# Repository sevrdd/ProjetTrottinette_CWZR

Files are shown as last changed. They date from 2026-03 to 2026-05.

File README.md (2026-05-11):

# Projet Trottinette

Projet éffectué par: Zachary Roy et William Champagne

Ce projet entreprend la conception d'un écran de tableau de bord pour une trottinette électrique. Ce tableau de bord est capable d'afficher les informations concernant la trottinette de façon efficace et précise sur un écran.

## Prérequis
Une trottinette fonctionelle à laquelle le module de tableau de bord est branché.

### Matériel
**1.** Boitier

**2.** PCB    

**3.** Écran (raspberry PI)

### Logiciel
**1.** STM32CubeIDE, CubeMX et VsCode
    - Tkinter et Pillow doivent être installé  
    
    pip install Pillow
    pip install tk 

**1.** Altium -> PCB 
    - Librairie Celestial utilisée
    - Librairie étudiante utilisée

**3.** Fusion 360 -> Modèle 3D 

### Limitations
L'affichage est limité à une vitesse de rafraîchissement de 5 Hz.

La version actuelle est limitée à une utilisation stationnaire dû à l'écran HDMI nécessitant une station fixe.

## Structure

### 3DModels
Cette section regroupe les [modèles 3D](<3DModels/>) nécessaires pour la fabrication et la manufacturation du PCB et du support associé à ce même PCB.

**1.** Modèle 3D de la [carte du tableau de bord.](<3DModels/>)

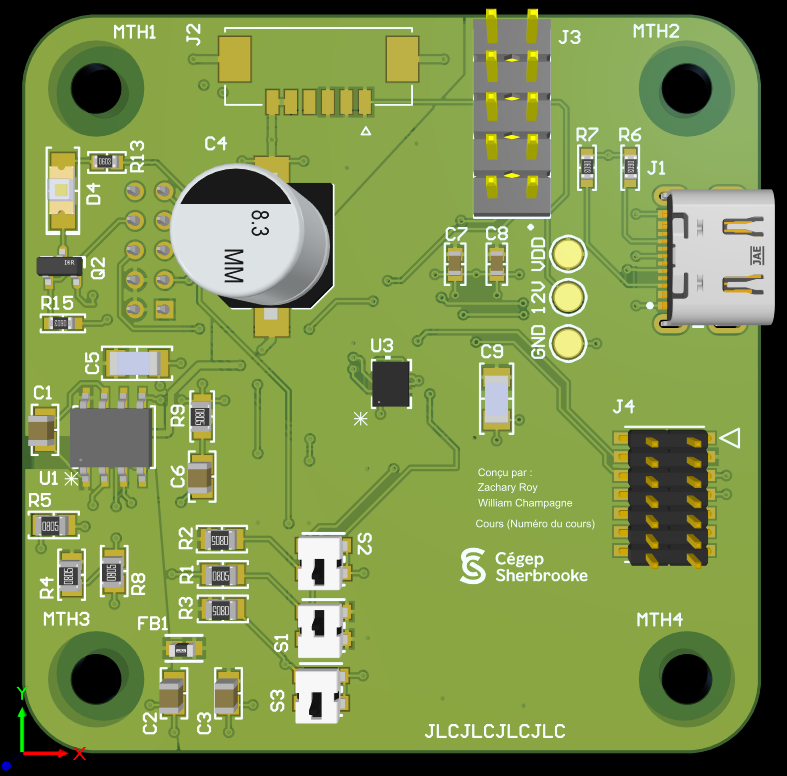
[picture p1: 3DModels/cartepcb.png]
Carte PCB


**2.** Modèle 3D du [support](<3DModels/>) pour la carte du tableau de bord et le raspberry pi. 

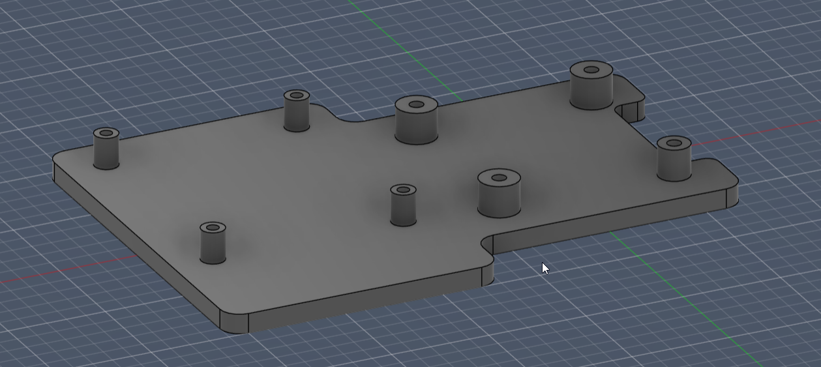
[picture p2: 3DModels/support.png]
Support


### Code
Cette section contient les fichiers code du [STM32](<Code/STM32/>) et du [Raspberry Pi](<Code/STM32/>)

- #### Raspberry Pi 3b
**tk_main.py** code gérant l'affichage de l'interface de l'utilisateur et la communication UART. 

**icons** fichier contenant les icones nécessaire pour l'affichage de l'interface utilisateur.

- #### STM32

**stm32_main.c** code "pass through" de l'information uart, faisant le pont entre la carte de contrôle et le raspberry pi.

### Datasheets
Cette section contient les diverses [datasheets](<Datasheets/>) utilisées pour la conception du schéma électrique. 

### Guides
Cette section contient les [guides](<Guides/>) pour utilisateur et développeur.

### Journal

Cette section contient le [journal](<Journal/>) de bord, la distribution des tâches au travers de la journée, les difficultés rencontrées ainsi que les solutions trouvées à ces mêmes problèmes.

### PCB
Cette [section](<PCB/>) contient les divers [symboles, footprints et modèles](<PCB/Symbols, footprints and models>) nécessaire pour la conception de la carte PCB ainsi que le plan de test complété. 

#### Fichier des symboles, footprints et modèles
- Fichier contenant les éléments nécessaires pour la conception de la carte PCB.

#### Plan de test
- Plan de test complété.

### Schéma
La section ["Schematics"](<Schematics/>) du dépôt github contient les shémas suivant : 

**1.** Shéma bloc *Vielle version* 

**2.** Shéma électrique 

**3.** Ordinogramme | Pour le code du raspberry pi 

## Utilisation
**1.** Brancher et allumer les composantes

**2.** Lancer le logiciel *tk_main.exe* (À faire un executable du code python)

**3.** Utiliser la trottinette

### Code STM32 et Python
La section "Code" du dépôt github contient les codes suivant : 
- stm32_main.c -> Code main du microcontrolleur STM32.
- tk_main.py -> Code python pour l'écran.

### Pour un utilisateur
Voir [Guide d'utilisateur](<Guides/guide_user.md>)

### Pour un developpeur
Voir [Guide de développement](<Guides/guide_dev.md>)

### Modifications à faire
- Révision du PCB
     - Changement du régulateur
           - 12V -> 5V Switching Régulateur, 5V -> 3V3 Régulateur LDO. Cela nous permet d'intégrer l'alimentation par USB-C  
     - Changer les branchements du connecteur de debug
- Boitié étanche
- Remplacer le Raspberry PI avec un écran adapter pour une trottinette. Cette modification nous rapprocherait du projet initiale décris par le client.
      - Nécessite un changement du code, du schéma électrique (+ Routage) et du boitié. Cela est donc une modification plus importante à faire lorsque les autres modifications sont éffectuées.

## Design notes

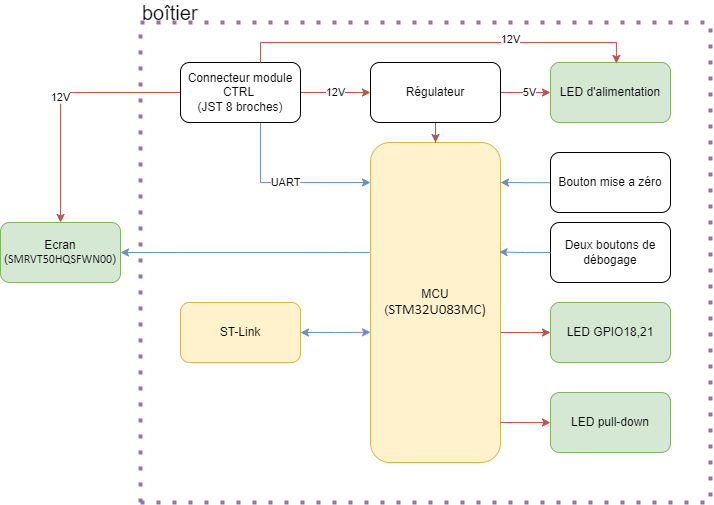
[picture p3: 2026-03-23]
Schematics/Shéma bloc.png

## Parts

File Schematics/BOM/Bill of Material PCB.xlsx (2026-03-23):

Bill of Material
Board | 1 |  | Concepteur Principal |  | Zachary Roy |  |  | 1
Cours | Cours (Numéro du cours) |  | Date du projet |  | 2026-02-26 |  |  | 00
Département | Technologies du génie électrique |  | Date de génération du BOM |  | 2026-02-26
Révision | 1.00 |  | Heure de génération du BOM |  | 4:27 PM
Nombre de PCB | 1 |  | Variant |  | None
Item # | Designator | #Column Name Error:' Layer | Description | Comment | Package / Case | Supplier 1 | Supplier Part Number 1 | Quantity | Quantity Total | Note
1 | C1 |  | CAP CER 0.1UF 50V X7R 0805 | 0.1 µF | 0805 (2012 Metric) | DigiKey | 311-4351-1-ND | 1 | 1
2 | C2, C3 |  | CAP CER 10UF 25V X5R 0805 | 10µF | 0805 (2012 Metric) | DigiKey | 478-10492-1-ND | 2 | 2
3 | C4 |  | CAP ALUM 100UF 20% 50V SMD | 100 µF | Radial, Can - SMD | DigiKey | 493-2226-1-ND | 1 | 1
4 | C5, C9 |  | CAP CER 10UF 100V X6S 1206 | 10 µF | 1206 (3216 Metric) | DigiKey | 445-C3216X6S2A106K160ACCT-ND | 2 | 2
5 | C6 |  | CAP CER 6800PF 50V X7R 0805 | 6800pF | 0805 (2012 Metric) | DigiKey | 478-1381-1-ND | 1 | 1
6 | C7 |  | CAP CER 4.7UF 25V X5R 0603 | 4.7 µF | 0603 (1608 Metric) | DigiKey | 1276-1900-1-ND | 1 | 1
7 | C8 |  | CAP CER 0.1UF 50V X7R 0603 | 0.1 µF | 0603 (1608 Metric) | DigiKey | 399-C0603C104K5RAC7411CT-ND | 1 | 1
8 | D1, D2 |  | LED GREEN DIFFUSED 1608 SMD | Green | 0603 (1608 Metric) | DigiKey | 846-SML-D12P8WT86CT-ND | 2 | 2
9 | D3, D4, D5, D6 |  | LED YELLOW 1206 SMD | Yellow | 1206 (3216 Metric) | DigiKey | 350-4363-1-ND | 4 | 4
10 | FB1 |  | Chip Ferrite Bead Array, 0603, 120Ω @ 100MHz, 25%, 0.03Ω, 3A | BLM18KG121TZ1D |  |  |  | 1 | 1
11 | J1 |  | CONN RCP USB2.0 TYP C 24P SMD RA | DX07S016JA1R1500 |  |  |  | 1 | 1
12 | J2 |  |  | 532610671 |  |  |  | 1 | 1
13 | J3 |  | Connector Header Through Hole 10 position 0.100" (2.54mm) | TSW-105-07-G-D |  |  |  | 1 | 1
14 | J4 |  | Description | FTSH-107-01-L-DV-K |  |  |  | 1 | 1
15 | J5 |  | CONN HEADER R/A 10POS 2MM | S10B-PHDSS (LF)(SN) |  |  |  | 1 | 1
16 | Q1, Q2 |  | MOSFET N-CH 20V 6.3A SOT-23 | IRLML6244TRPBF |  |  |  | 2 | 2
17 | Q3, Q4 |  | MOSFET P-CH 12V 4.3A SOT-23 | IRLML6401TRPBF |  |  |  | 2 | 2
18 | R1, R2, R3 |  | RES SMD 10K OHM 0.5% 1/4W 0805 | 10 kOhms | 0805 (2012 Metric) | DigiKey | RNCF0805DTE10K0CT-ND | 3 | 3
19 | R4 |  | RES SMD 3K OHM 0.1% 1/4W 0805 | 3 kOhms | 0805 (2012 Metric) | DigiKey | P20646CT-ND | 1 | 1
20 | R5 |  | RES 47K OHM 1% 1/3W 0805 | 47 kOhms | 0805 (2012 Metric) | DigiKey | A130497CT-ND | 1 | 1
21 | R6, R7, R14, R15, R19, R21 |  | RES SMD 5.1K OHM 1% 1/10W 0603 | 5.1 kOhms | 0603 (1608 Metric) | DigiKey | YAG3621CT-ND | 6 | 6
22 | R8 |  | RES SMD 1.3K OHM 0.5% 1/4W 0805 | 1.3 kOhms | 0805 (2012 Metric) | DigiKey | P21031CT-ND | 1 | 1
23 | R9 |  | RES SMD 10K OHM 0.5% 1/8W 0805 | 10 kOhms | 0805 (2012 Metric) | DigiKey | 311-2699-1-ND | 1 | 1
24 | R10 |  | RES SMD 150 OHM 0.1% 1/4W 0805 | 150 Ohms | 0805 (2012 Metric) | DigiKey | A110464CT-ND | 1 | 1
25 | R11 |  | RES SMD 500 OHM 0.05% 1/4W 0805 | 500 Ohms | 0805 (2012 Metric) | DigiKey | PLT0805-500ACT-ND | 1 | 1
26 | R12, R13, R18, R20 |  | RES SMD 100 OHM 5% 1/4W 0603 | 100 Ohms | 0603 (1608 Metric) | DigiKey | RHM100DCT-ND | 4 | 4
27 | R16, R17 |  | RES SMD 4.7K OHM 5% 1/2W 0805 | 4.7 kOhms | 0805 (2012 Metric) | DigiKey | 541-2866-1-ND | 2 | 2
28 | S1, S2, S3 |  | SWITCH DETECTOR SPST-NO 1MA 5V | HDT0001 |  | DigiKey | 401-1733-1-ND | 3 | 3
29 | U1 |  | Description | BD9G341AEFJ-E2 |  |  |  | 1 | 1
30 | U2 |  | Ultra-low-power Arm Cortex-M0+ MCU with 256 Kbytes of Flash memory, LCD, USB, AES, 56 MHz CPU | STM32U083CCT6 |  |  |  | 1 | 1
31 | U3 |  | Description | BMI323 |  |  |  | 1 | 1
Commentaires ou instruction spécialies

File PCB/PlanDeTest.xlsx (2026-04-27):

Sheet: Tests
 | Plan de tests
Nom du PCB |  | Préparé par | Zachary Roy
Cours | 243-454-SH | Testeur | Zachary Roy
Département | Technologies du génie électrique | date | 2026-03-20
Révision du PCB | 0.00
Fonction | Description du test | Résultat | Raison réussite ou échec | modification effectuée | Nouveau résultat | Commentaire
Unitaire | Faire une inspection visuelle de la carte et des composantes | Échec | Plusieur composante sont soit trop petite ou trop grosse pour leur traces | J'ai utilisé des fils pour les connecter | Réussi
Unitaire | Tester la résistance entre le testpoint 12V et GND. Elle devrait être dans les Kohm | Réussi | J'ai 40 Kohm
Unitaire | Tester la résistance entre le testpoint VDD et GND. Elle devrait être dans les kohm | Réussi | 3.8 Kohm
Unitaire | Assemblé le boitier avec le PCB | Échec | les trous trop éloigner | Une version 2 du boititer est faite | Réussi | Il s'assemble bien
Fonctionnel | Avec un multimètre, tester les bouttons S1,S2,S3. S1 est pull-down, S2,S3 sont pull-up | Échec | On a seulement le boutton S2 à cause que les traces sont plus petite que les bouttons | Aucune | Réussi
Intégration | Connecter le PCB à 12V, soit avec le connecteur J5 ou avec le testpoint 12V. Les lumières D1,D2 devrait allumer. | Échec | Seulement la diode D2 allume | Le régulateur en fonctionne pas. On a branché un fil au 3V3 | Échec | On a une alimentation 3V3, mais notre 12V est devenue 2.5V. Les deux lumières allume
Intégration | Connecter un ST-LINK au connecteur J4. | Échec | Le connecteur est flipé | Prière a zeus | Échec | Tristess et désolation
Intégration | Pousser le code. | Échec | Incapable de détecté le MCU part le port USB-C | Ajouté un fil pour mettre ne mode boot | Échec | On ne détecte pas encore le MCU
Fonctionnel | Avec le code, voir si le STM voie les communication UART du controlleur | Échec | On est incapable de pousser le code dans le STM32
Fonctionnel | Avec le code, voir les valeur du IMU | Échec | On est incapable de pousser le code dans le STM32
Fonctionnel | Bouger le PCB toute en lisant la pin GPIO21. Elle devrait changer quand le pcb bouge brusquement | Échec | On est incapable de pousser le code dans le STM32
Fonctionnel | Sur le raspberryPI, executer le code .PY | Échec | Il manque la librairie CustomTk | Enlever la librairie CustomTk du code | Réussi | Le code execute
Intégration | Connecter le PCB au RaspberryPI. Le PI doit commencer a détecter des données sur le port UART | Échec | On est incapable de pousser le code dans le STM32
Intégration | L'affichage du RaspberryPI affiche les données de la trotinette | Échec | On est incapable de pousser le code dans le STM32

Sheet: Modification 2ième version
# | Modification suggérée | Explication
1 | Mettre un plan entre F* et FB1 | Dans V1, la trace entre les deux est rated 0.8A. J'ai dût mettre un fil pour que ça marche
2
3
4
5
6
7
8
9
10
11
12
13

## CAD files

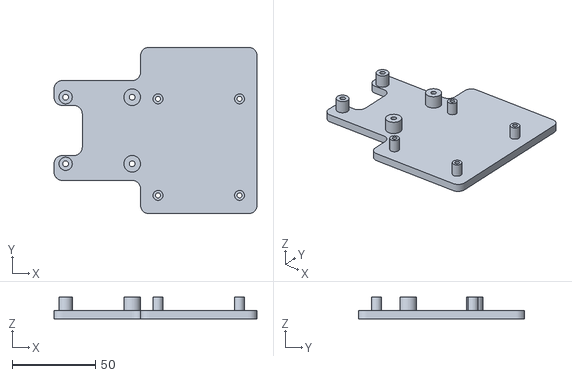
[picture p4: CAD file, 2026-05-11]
3DModels/Support_MODEL.stl
122.0 x 100.0 x 13.0

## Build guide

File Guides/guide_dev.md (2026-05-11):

## Guide de développement
### Description
Ceci est le guide de développement. Il contient les branchements du module tableau de bord ainsi qu'une explication complète de son affichage, de son branchement, du déboggage ainsi qu'un résumé du code.

Pour retourner au README, cliquer [ici](<../README.md>)

### Branchement

**1.** Alimenter le PCB avec l'alimentation 12V.
 
**2.** Brancher le câble HDMI dans le port HDMI du Raspberry Pi.
 
**3.** Alimenter le Raspberry Pi avec un câble USB-C.
 
**4.** Brancher le BMI avec un câble I2C | Exemple : [4399](https://www.digikey.ca/en/products/detail/adafruit-industries-llc/4399/10824268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)

**5.** Brancher un câble style Arduino [1956](https://www.digikey.ca/en/products/detail/adafruit-industries-llc/1956/6827089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) entre la patte 1 du header (Tx) *J3* sur la carte STM32 et la patte 8 du Raspberry Pi. Refaire ces mêmes opérations entre la patte 3 du header (Rx) *J3* sur la carte STM32 et la patte 10 du Raspberry Pi.

Cela établit la communication UART entre la carte STM32 et le Raspberry Pi.

Images des pattes de la carte STM32 et du Raspberry Pi :

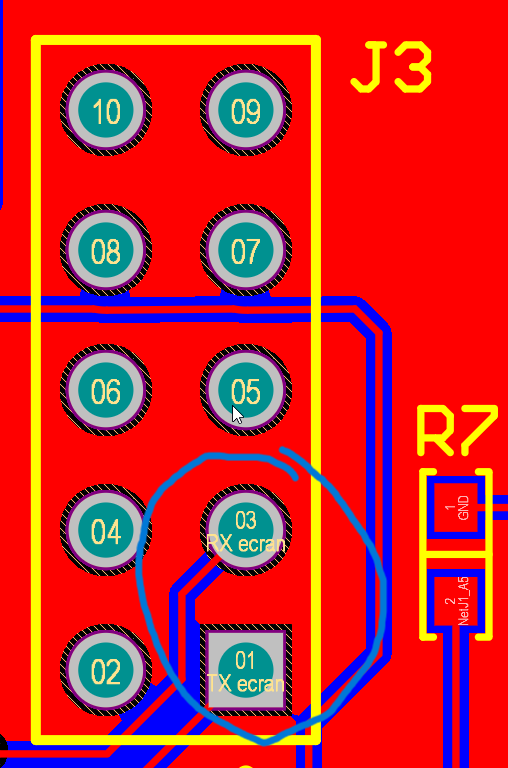
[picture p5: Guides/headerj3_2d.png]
Voir image ici HeaderJ3_2D


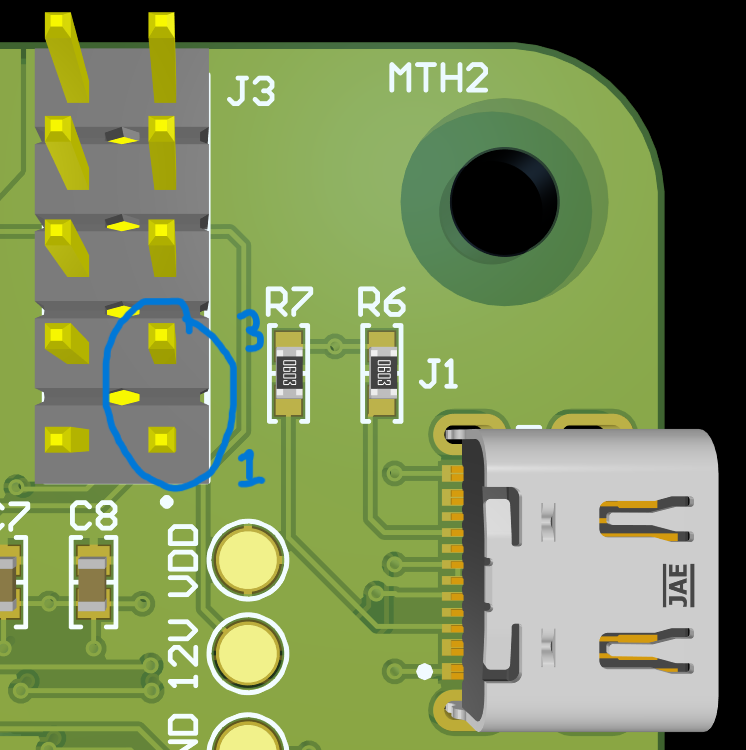
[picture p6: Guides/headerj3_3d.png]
Version 3D HeaderJ3_3D


### Branchement optionnel
**Programmation et déboggage :**

**1.** Brancher un câble USB-C dans le connecteur USB-C pour accéder au déboggage (port série) et à la programmation.
- Nécessite d'activer la bootstrap (*Switch 1*) pour entrer en mode programmation.

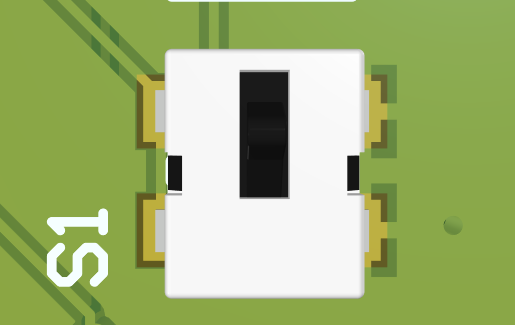
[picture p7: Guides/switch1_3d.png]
Image S1 Switch1


**2.** Brancher le câble [STLINK-V3MINIE](https://www.digikey.ca/en/products/detail/stmicroelectronics/STLINK-V3MINIE/16284301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) pour accéder au déboggage (CubeIDE) et à la programmation (CubeIDE).

### Déboggage

#### DELs
**1.** D1 s'allume quand l'alimentation VDD (3V3) est présente (alimentation debug).

**2.** D2 s'allume quand l'alimentation 12V est présente (alimentation debug).

**3.** D3 s'allume quand un signal vers GPIO18 (du tableau de bord vers la carte de contrôle) est envoyé.

**4.** D4 s'allume quand un signal vers GPIO21 (du tableau de bord vers la carte de contrôle) est envoyé.

**5.** D5 s'allume quand un signal vers GPIO0 (du tableau de bord vers la carte de contrôle) est envoyé.

**6.** D6 et D7 sont des DELs de déboggage programmables (à partir du code STM32).

#### Switches
**1.** La switch *S2* (NRST | RESET) permet de réinitialiser le tableau de bord.

**2.** La switch *S3* (RESET | CTRL) permet de réinitialiser la carte de contrôle.

**3.** La switch *S1* (BOOT0) est une bootstrap permettant de configurer le mode de démarrage (mode programmation et mode *Firmware* | mode normal).

#### Points de test
**1.** Un point de test est disponible pour mesurer la tension de l'alimentation 12V.

**2.** Un autre point de test est disponible pour accéder au ground.

**3.** Il est possible d'analyser l'échange de données entre la carte du tableau de bord et le Raspberry Pi en utilisant la patte 1 du header (Tx) *J3* et la patte 3 du header (Rx) *J3*. Cependant, l'analyse des données ne peut pas se faire en même temps que la connexion avec le Raspberry Pi (à moins d'utiliser un splitter ou une autre méthode semblable).

### Résumé du code

Le code commence par tenter d'accéder au port UART. Ensuite, il traite les données (sous format JSON) et effectue la logique vue dans l'ordinogramme. Il affiche ensuite les informations sous forme d'interface utilisateur.

#### Ordinogramme

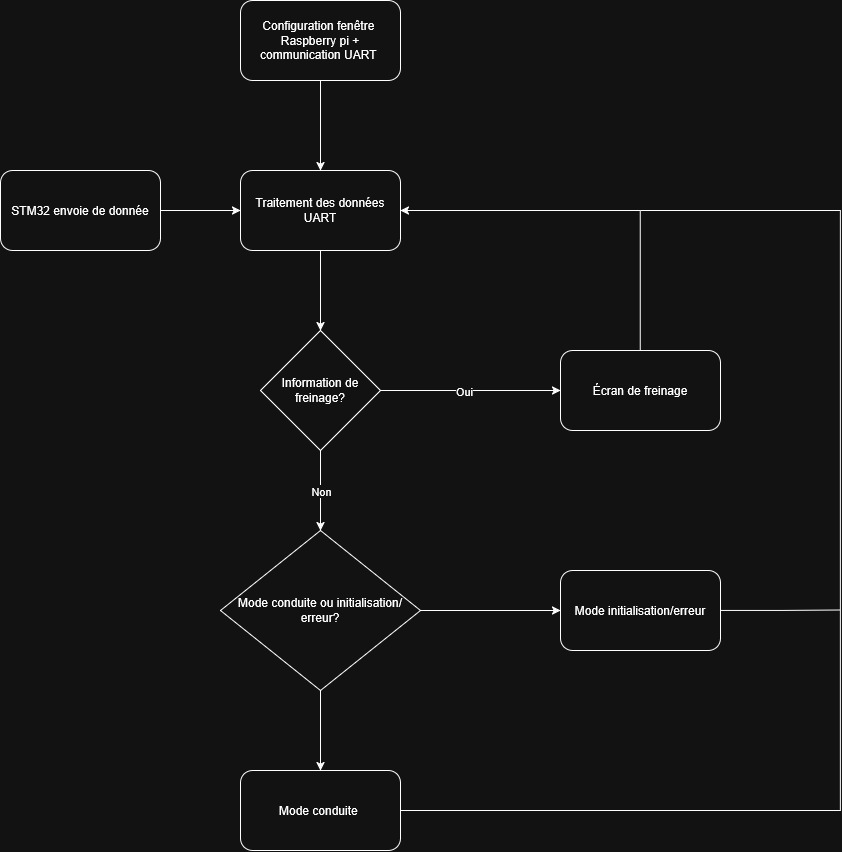
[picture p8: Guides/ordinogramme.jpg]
Ordinogramme


#### tk_main_exp.py
*L'ensemble des fonctions du code Raspberry Pi est contenu dans la classe :*

```python
class speedometer(ttk.Frame):
```

*Les fonctions contenues dans cette classe sont les suivantes :*

```python
__init__(self, master, max_speed=51, size=1000)
```

Cette fonction gère l'initialisation des divers éléments présents dans l'interface utilisateur (cadres, texte, icônes, etc.) ainsi que les paramètres de configuration de la fenêtre.

- `max_speed` : vitesse maximale de la trottinette. Cela ajuste le ratio vitesse par rapport à la complétion du cercle.
- `size` : grosseur de la fenêtre (même grandeur pour X et Y).

```python
set_power(self, power_percent)
```

Cette fonction gère la configuration graphique de l'arrière-plan selon la puissance fournie au moteur (le pourcentage fourni et non l'ampérage fourni).

```python
set_speed(self, speed)
```

Cette fonction gère les calculs nécessaires pour l'affichage de l'indicateur de vitesse.

```python
show_data_drive(self, temps, battery, motor_current, motor_mode, power_percent, lights, state)
show_data_other(self, error_code, key_state, e_stop, state, fwver, hwver)
```

Ces fonctions gèrent la sélection des éléments à afficher à l'utilisateur dépendamment du mode.

```python
show_break_screen(self)
```

Cette fonction gère l'affichage de l'écran de freinage.

```python
read_UART(self)
```

Cette fonction lit et traite les informations transmises par le tableau de bord. Cette fonction dicte le mode d'affichage (normal, initialisation/erreur et freinage).

```python
try:
    uart_conf = serial.Serial("/dev/serial0", 9600, timeout=1)
except:
    print("Port not found, using dummy data instead.")
```

Cette section du code tente d'accéder au port UART. Si le port n'est pas disponible, des données fictives (*dummy data*) sont utilisées à la place.

#### Code STM32 `main.c`

```c
if(HAL_UART_Receive(&huart1, &byte, 1, 0) == HAL_OK) // agit comme pass-through bridge
{
    HAL_UART_Transmit(&huart2, &byte, 1, HAL_MAX_DELAY);
}
```

Cette fonction agit comme un *pass-through bridge* (renvoie directement les informations reçues par la carte de contrôle vers le Raspberry Pi).

### Codes d'erreurs

En mode erreur (*ERROR*), une variété de codes d'erreurs différents peuvent s'afficher à l'écran. Ci-dessous se présente une liste des erreurs possibles avec une courte description.

## Fault Status

**FAULT:** au moins une erreur active.

### General Driver Faults
- **VDS_OCP:** DRV - VDS monitor overcurrent
- **GDF:** DRV - gate drive fault
- **UVLO:** DRV - undervoltage lockout
- **OTSD:** DRV - overtemperature shutdown
- **OTW:** DRV - overtemperature warning
- **CPUV:** DRV - charge pump undervoltage fault condition

### Phase A Faults
- **VDS_HA:** DRV - VDS overcurrent fault on the A high-side
- **VDS_LA:** DRV - VDS overcurrent fault on the A low-side
- **SA_OC:** DRV - overcurrent on phase A sense amplifier
- **VGS_HA:** DRV - gate drive fault on the A high-side MOSFET
- **VGS_LA:** DRV - gate drive fault on the A low-side MOSFET

### Phase B Faults
- **VDS_HB:** DRV - VDS overcurrent fault on the B high-side
- **VDS_LB:** DRV - VDS overcurrent fault on the B low-side
- **SB_OC:** DRV - overcurrent on phase B sense amplifier
- **VGS_HB:** DRV - gate drive fault on the B high-side MOSFET
- **VGS_LB:** DRV - gate drive fault on the B low-side MOSFET

### Phase C Faults
- **VDS_HC:** DRV - VDS overcurrent fault on the C high-side
- **VDS_LC:** DRV - VDS overcurrent fault on the C low-side
- **SC_OC:** DRV - overcurrent on phase C sense amplifier
- **VGS_HC:** DRV - gate drive fault on the C high-side MOSFET
- **VGS_LC:** DRV - gate drive fault on the C low-side MOSFET

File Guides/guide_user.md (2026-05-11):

## Guide d'utilisateur
### Description
Ceci est le guide d'utilisateur. Il contient les branchements du module tableau de bord ainsi qu'une explication complète de son affichage.

Pour retourner au README, cliquer [ici](<../README.md>)

### Branchement

**1.** Alimenter le PCB avec l'alimentation 12V.
 
**2.** Brancher le câble HDMI dans le port HDMI du Raspberry Pi.

### Affichage

**En mode DRIVE :**

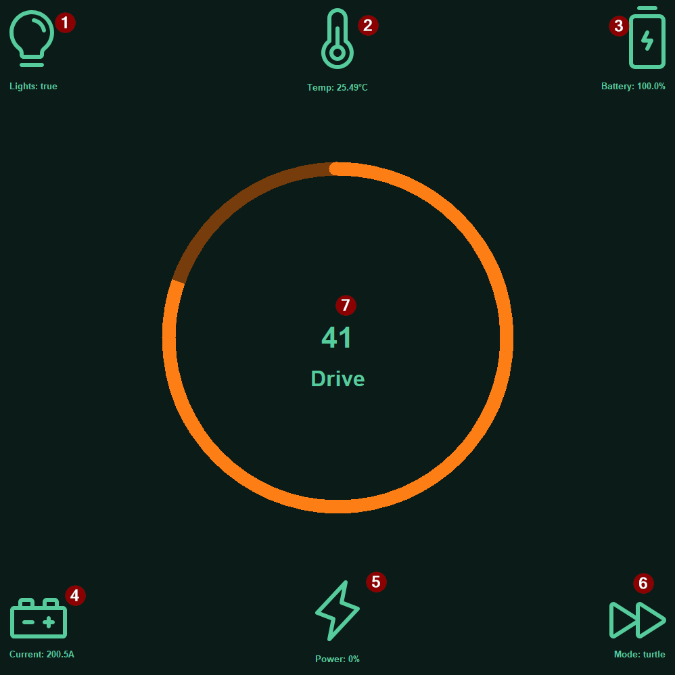
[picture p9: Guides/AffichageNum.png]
Affichage DRIVE


**1.** Affiche l'état des lumières.
  
**2.** Affiche la température.
  
**3.** Affiche l'état de la batterie.
  
**4.** Affiche le courant des moteurs (A).
  
**5.** Affiche la puissance utilisée.
  
**6.** Affiche le mode d'utilisation (*turtle* ou *rabbit*).
  
**7.** Affiche la vitesse (km/h).

**En mode INIT et ERROR :**

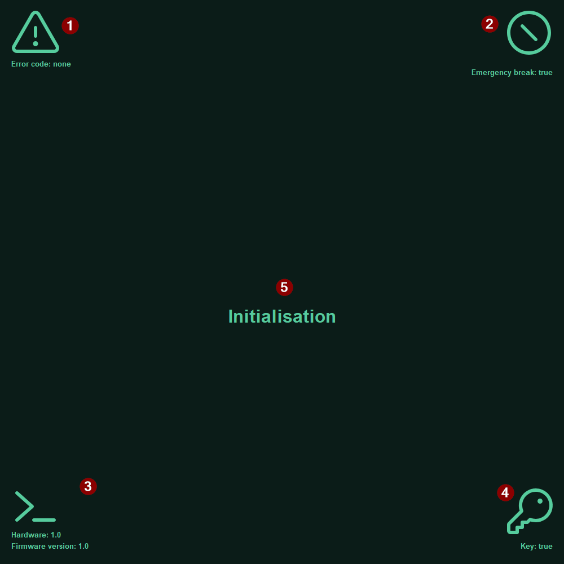
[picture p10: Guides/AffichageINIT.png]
Affichage INIT


**1.** Affiche les codes d'erreurs.
  
**2.** Affiche l'état des freins d'urgence.
  
**3.** Affiche les versions du programme.
  
**4.** Affiche l'état des clés.
  
**5.** Affiche le mode.

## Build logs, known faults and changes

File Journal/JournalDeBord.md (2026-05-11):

## 16 Février
- Création du projet Altium
- Création du repo GitHub
- Début de la création du schéma électrique
    - Recherche des composantes nécessaires et des *datasheets* associées
- Installation de TouchGFX
    - Configuration de l'environnement et recherche sur la librairie

## 23 Février
- Finalisation du schéma électrique
    - Sélection du mode de communication (header choisi pour plus de polyvalence)
    - Examen par les pairs
- Création du BOM et envoi du BOM
- Recherche sur TouchGFX

## 9 Mars
- Début du PCB
- Recherche et début du code Python Tkinter
    - Structure générale créée, mais non fonctionnelle

## 16 Mars
- Finalisation du PCB et envoi en fabrication
- Finalisation du développement du code
    - Fonctionnel avec un petit système de simulation prêt

## 23 Mars
- Installation des librairies et configuration de l'environnement de déboggage Python pour le Raspberry Pi
- Test du code sur Raspberry Pi (succès)
- Début du modèle 3D

## 30 Mars
- Finalisation du boîtier et envoi en fabrication
- Début du guide d'utilisateur, de la documentation, du plan de test, etc.

## 13 Avril
- Assemblage du PCB
    - Les DELs étaient plus petites que les pads, donc un *bridge* avec un fil a dû être effectué
    - Les boutons étaient beaucoup trop gros pour les pads, donc seul le bouton de reset du STM32 a été installé
- Continuation de la documentation, du guide d'utilisateur, du plan de test, de la conception de l'ordinogramme, etc.

## 20 Avril
- Le boîtier a été envoyé en production
- Du contenu a été ajouté au README
- L'assemblage du PCB est terminé
    - Aucun fil disponible pour continuer le plan de test

## 27 Avril
- Un fil a été trouvé pour continuer le plan de test du PCB
- Les trous du boîtier pour fixer le PCB étaient trop éloignés l'un de l'autre
    - Après modifications, une nouvelle version a été envoyée en production

## 4 Mai
- Assemblage terminé
- Test de la carte
    - Le régulateur ne fonctionne pas. Un *bypass* a été effectué en alimentant directement le point de test 3V3, mais le STM32 ne s'allume pas (ou n'est pas reconnu par l'ordinateur)
    - Le Raspberry Pi ne laisse pas le code accéder au port UART. Malgré plusieurs essais, le port UART reste bloqué
- Finalisation du plan de test (complété et envoyé)

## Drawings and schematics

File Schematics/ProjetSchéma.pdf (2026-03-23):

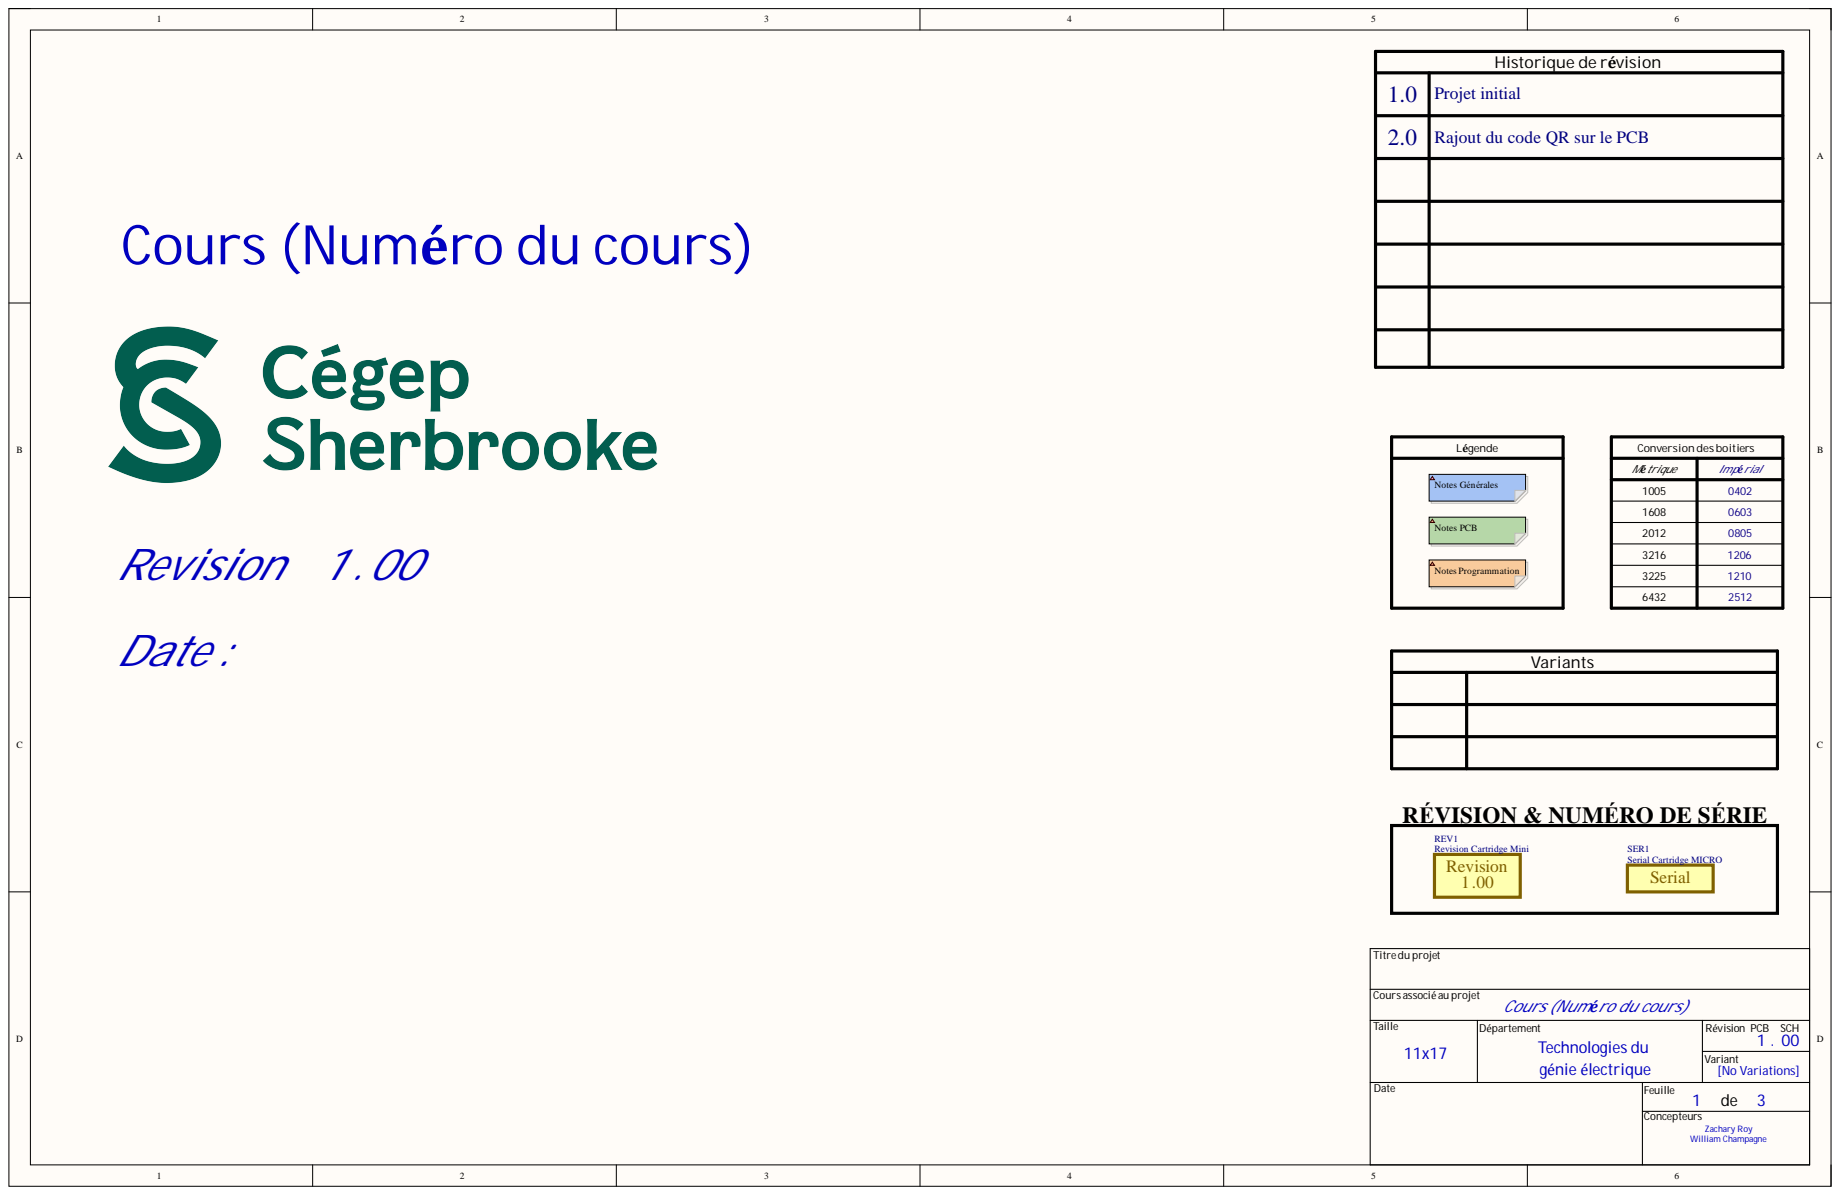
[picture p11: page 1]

1.0 | Projet initia l

2.0 | Rajo ut d u c o d e QR sur le PCB

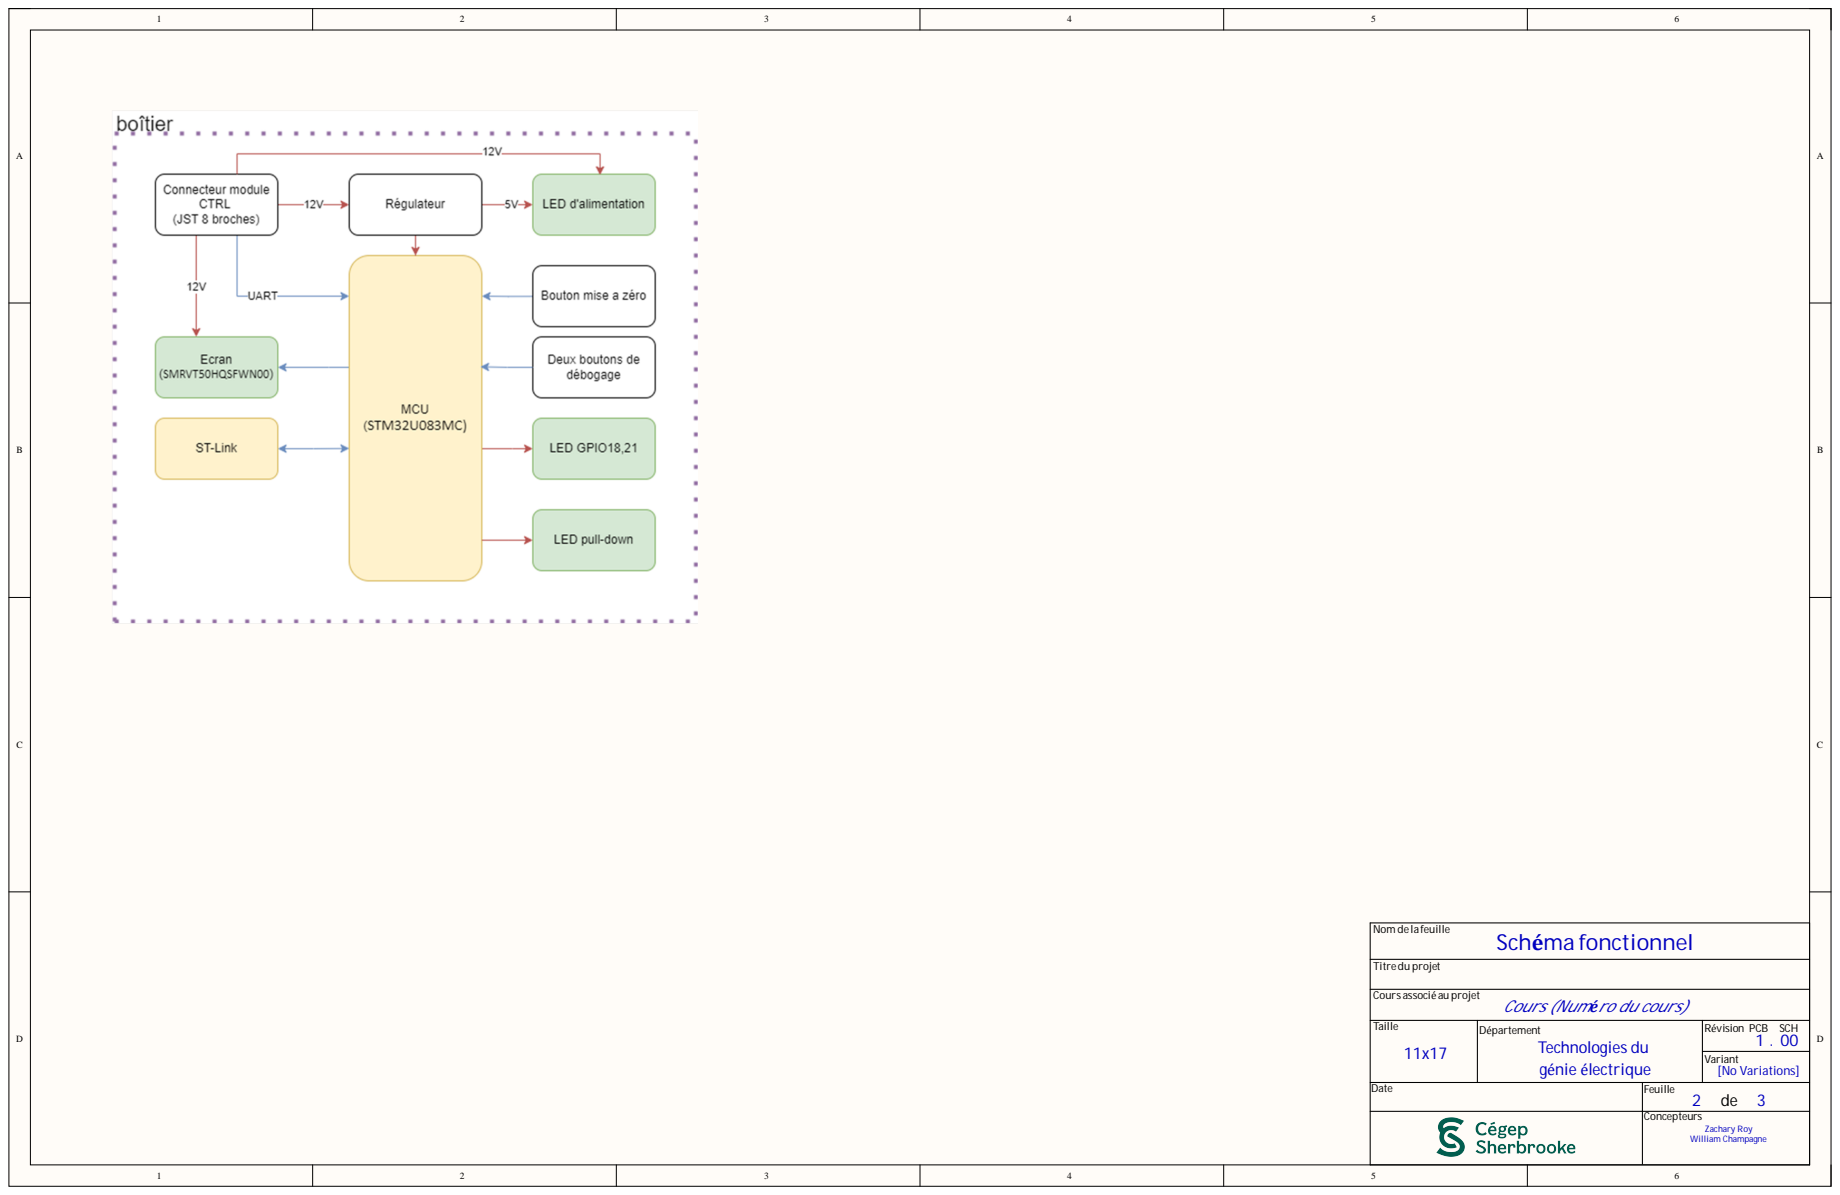
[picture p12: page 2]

Nom de la feuille

Cours associé au projet

Cours (Numéro du cours)

Date | Feuille 2 de Concepteurs 3

Zachary Roy William Champagne

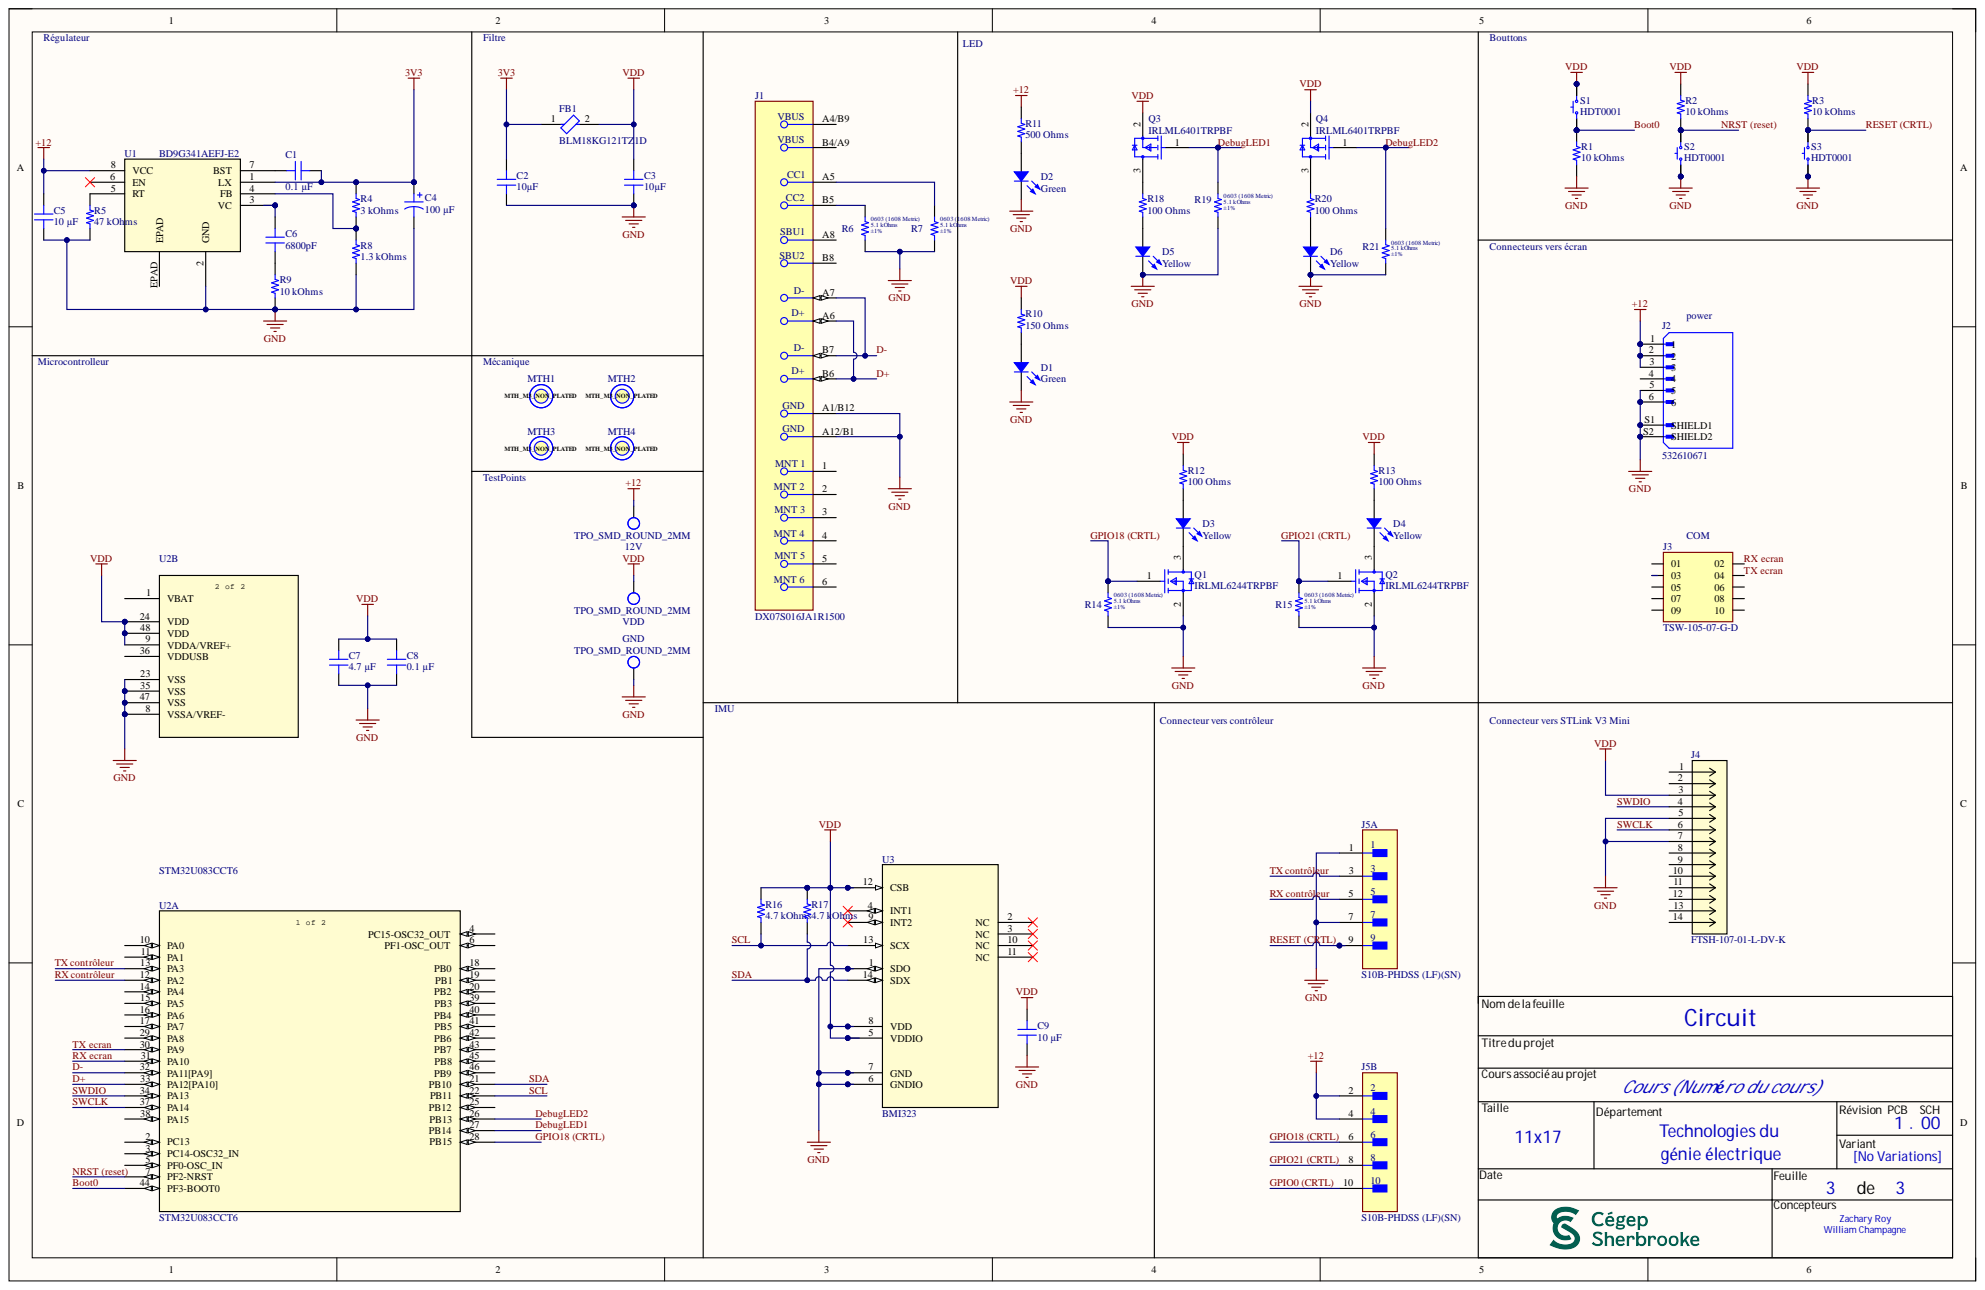
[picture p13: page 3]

necteur vers STLink V3 Min

SDX 14

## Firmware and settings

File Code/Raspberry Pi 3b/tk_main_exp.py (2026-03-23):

import tkinter as tk
import tkinter.ttk as ttk
import serial
import json
import os 
from PIL import Image, ImageTk

# setting up uart config 
try:
    uart_conf = serial.Serial("/dev/serial0", 9600, timeout=1)
except:
    print("port error or smth")

class speedometer(ttk.Frame):

    def __init__(self, master, max_speed=51, size=1000):
        super().__init__(master)

        self.max_speed = max_speed
        self.size = size

        self.canvas = tk.Canvas(self, width=size, height=size, bg="black", highlightthickness=0)
        self.canvas.pack()

        padding = 250

        self.brake_overlay = self.canvas.create_rectangle(
            0, 0, size, size,
            fill="red",
            state="hidden"
        )

        self.power_bar = self.canvas.create_rectangle(
            0, 0,
            size, size,  # starts with 0 width
            fill="#00f2ff", outline=""
        )


        # speedometer back
        self.speedometer_back = self.canvas.create_oval(
            padding, padding,
            size-padding, size-padding,
            outline="#763c0c",
            width=20
        )

        # speedometer front
        self.speedometer_front = self.canvas.create_arc(
            padding, padding,
            size-padding, size-padding,
            start=90,
            extent=0,
            style="arc",
            outline="#fd7e14",
            width=20
        )

        # current
        self.current_text = self.canvas.create_text(
            15, size - 40,
            text="Current: --",
            fill="#56cc9d",
            font=("Space Grotesk", 10, "bold"),
            anchor="nw"
        )
        base_path = os.path.dirname(__file__)
        icon_path = os.path.join(base_path, "icons", "car-battery.png")
        self.current_icon = Image.open(icon_path)
        self.current_icon_tk = ImageTk.PhotoImage(self.current_icon)
        self.current_img = self.canvas.create_image(10, size - 130, image=self.current_icon_tk, anchor="nw")

        # motor mode
        self.mode_text = self.canvas.create_text(
            size - 15, size - 40,
            text="Mode: --",
            fill="#56cc9d",
            font=("Space Grotesk", 10, "bold"),
            anchor="ne"
        )
        base_path = os.path.dirname(__file__)
        icon_path = os.path.join(base_path, "icons", "fast-forward.png")
        self.mmode_icon = Image.open(icon_path)
        self.mmode_icon_tk = ImageTk.PhotoImage(self.mmode_icon)
        self.mmode_img = self.canvas.create_image(size - 110, size - 130, image=self.mmode_icon_tk, anchor="nw")

        # speed
        self.speed_text = self.canvas.create_text(
            size/2, size/2,
            text="",
            fill="#56cc9d",
            font=("Space Grotesk", 32, "bold")
        )

        # temps
        self.temp_text = self.canvas.create_text(
            size/2, 130,
            text="Temp: --",
            fill="#56cc9d",
            font=("Space Grotesk", 10, "bold"),
            anchor="center"
        )
        base_path = os.path.dirname(__file__)
        icon_path = os.path.join(base_path, "icons", "thermometer-simple.png")
        self.temp_icon = Image.open(icon_path)
        self.temp_icon_tk = ImageTk.PhotoImage(self.temp_icon)
        self.temp_img = self.canvas.create_image(size/2, 10, image=self.temp_icon_tk, anchor="n")

        # battery
        self.battery_text = self.canvas.create_text(
            size - 15, 120,
            text="Battery: --",
            fill="#56cc9d",
            font=("Space Grotesk", 10, "bold"),
            anchor="ne"
        ) ## loading image
        base_path = os.path.dirname(__file__)
        icon_path = os.path.join(base_path, "icons", "battery-charging-vertical.png")
        self.battery_icon = Image.open(icon_path)
        self.battery_icon_tk = ImageTk.PhotoImage(self.battery_icon)
        self.battery_img = self.canvas.create_image(size - 90, 10, image=self.battery_icon_tk, anchor="nw")

        # power percent
        self.power_percent = self.canvas.create_text(
            size/2, size - 25,
            text="Power: --",
            fill="#56cc9d",
            font=("Space Grotesk", 10, "bold"),
            anchor="center"
        )
        base_path = os.path.dirname(__file__)
        icon_path = os.path.join(base_path, "icons", "lightning.png")
        self.lightning_icon = Image.open(icon_path)
        self.lightning_icon_tk = ImageTk.PhotoImage(self.lightning_icon)
        self.power_img = self.canvas.create_image(size/2, size - 96, image=self.lightning_icon_tk, anchor="center")

        # lights
        self.lights = self.canvas.create_text(
            15, 120,
            text="Lights: --",
            fill="#56cc9d",
            font=("Space Grotesk", 10, "bold"),
            anchor="nw"
        )
        base_path = os.path.dirname(__file__)
        icon_path = os.path.join(base_path, "icons", "lightbulb.png")
        self.lighting_icon = Image.open(icon_path)
        self.lighting_icon_tk = ImageTk.PhotoImage(self.lighting_icon)
        self.light_img = self.canvas.create_image(0, 10, image=self.lighting_icon_tk, anchor="nw")

        # err_code
        self.err_code = self.canvas.create_text(
            20, 105,
            text="Error code: --",
            fill="#56cc9d",
            font=("Space Grotesk", 10, "bold"),
            anchor="nw"
        )
        base_path = os.path.dirname(__file__)
        icon_path = os.path.join(base_path, "icons", "warning.png")
        self.err_code_icon = Image.open(icon_path)
        self.err_code_icon_tk = ImageTk.PhotoImage(self.err_code_icon)
        self.err_code_img = self.canvas.create_image(15, 10, image=self.err_code_icon_tk, anchor="nw")

        # keys
        self.key_state = self.canvas.create_text(
            size - 20, size - 40,
            text="Key: --",
            fill="#56cc9d",
            font=("Space Grotesk", 10, "bold"),
            anchor="ne"
        )
        base_path = os.path.dirname(__file__)
        icon_path = os.path.join(base_path, "icons", "key.png")
        self.key_icon = Image.open(icon_path)
        self.key_icon_tk = ImageTk.PhotoImage(self.key_icon)
        self.key_img = self.canvas.create_image(size - 110, size - 140, image=self.key_icon_tk, anchor="nw")

        # emergency stop
        self.e_stop = self.canvas.create_text(
            size - 20, 120,
            text="Emergency stop: --",
            fill="#56cc9d",
            font=("Space Grotesk", 10, "bold"),
            anchor="ne"
        )
        base_path = os.path.dirname(__file__)
        icon_path = os.path.join(base_path, "icons", "prohibit-inset.png")
        self.estop_icon = Image.open(icon_path)
        self.estop_icon_tk = ImageTk.PhotoImage(self.estop_icon)
        self.estop_img = self.canvas.create_image(size - 110, 10, image=self.estop_icon_tk, anchor="nw")

        # brakes
        base_path = os.path.dirname(__file__)
        icon_path = os.path.join(base_path, "icons", "prohibit1.png")
        self.brake_icon = Image.open(icon_path)
        self.brake_icon_tk = ImageTk.PhotoImage(self.brake_icon)
        self.brake_img = self.canvas.create_image(size/2, size/2, image=self.brake_icon_tk, anchor="center")
        
        # firmware version
        self.fwver = self.canvas.create_text(
            20, size - 40,
            text="Firmware Version: --",
            fill="#56cc9d",
            font=("Space Grotesk", 10, "bold"),
            anchor="nw"
        )
        base_path = os.path.dirname(__file__)
        icon_path = os.path.join(base_path, "icons", "terminal.png")
        self.fwver_icon = Image.open(icon_path)
        self.fwver_icon_tk = ImageTk.PhotoImage(self.fwver_icon)
        self.fwver_img = self.canvas.create_image(15, size - 150, image=self.fwver_icon_tk, anchor="nw")

        # hardware version
        self.hwver = self.canvas.create_text(
            20, size - 60,
            text="Hardware Version: --",
            fill="#56cc9d",
            font=("Space Grotesk", 10, "bold"),
            anchor="nw"
        )

        # system state
        self.sysstate = self.canvas.create_text(
            size/2, size/2 + 60,
            text="",
            fill="#56cc9d",
            font=("Space Grotesk", 24, "bold")
        )

    def set_power(self, power_percent):
        brightness = int((50 * power_percent / 100) + 35)  
        r = int(0x56 * brightness / 255)
        g = int(0xcc * brightness / 255)
        b = int(0x9d * brightness / 225)
        color = f"#{r:02x}{g:02x}{b:02x}"
        self.canvas.itemconfig(self.power_bar, fill=color)

    # speedometer and speed data packing
    def set_speed(self, speed):
        ratio = speed / self.max_speed
        extent = -360 * ratio   # clockwise needs negative values 

        self.canvas.itemconfig(self.speedometer_front, extent=extent)
        self.canvas.itemconfig(self.speed_text, text=str(speed))

    # data packing
    def show_data_drive(self, temps, battery, motor_current, motor_mode, power_percent, lights, state):
        # hiding irrelevant data 
        self.canvas.itemconfig(self.brake_overlay, state="hidden")
        self.canvas.itemconfig(self.err_code, state="hidden")
        self.canvas.itemconfig(self.key_state, state="hidden")
        self.canvas.itemconfig(self.e_stop, state="hidden")
        self.canvas.itemconfig(self.estop_img, state="hidden")
        self.canvas.itemconfig(self.err_code_img, state="hidden")
        self.canvas.itemconfig(self.key_img, state="hidden")
        self.canvas.itemconfig(self.brake_img, state="hidden")
        self.canvas.itemconfig(self.fwver_img, state="hidden")
        self.canvas.itemconfig(self.fwver, state="hidden")
        self.canvas.itemconfig(self.hwver, state="hidden")

        self.set_power(power_percent)

        # showing relevant data
        self.canvas.itemconfig(self.temp_text, text=f"Temp: {temps}°C", state="normal")
        self.canvas.itemconfig(self.battery_text, text=f"Battery: {battery}%", state="normal")
        self.canvas.itemconfig(self.current_text, text=f"Current: {motor_current}A", state="normal")
        self.canvas.itemconfig(self.mode_text, text=f"Mode: {motor_mode}", state="normal")
        self.canvas.itemconfig(self.power_percent, text=f"Power: {power_percent}%", state="normal")
        self.canvas.itemconfig(self.lights, text=f"Lights: {lights}", state="normal")
        self.canvas.itemconfig(self.lights, text=f"Lights: {lights}", state="normal")
        self.canvas.itemconfig(self.sysstate, text=f"{state}", state="normal")
        self.canvas.itemconfig(self.light_img, state="normal")
        self.canvas.itemconfig(self.current_img, state="normal")
        self.canvas.itemconfig(self.battery_img, state="normal")
        self.canvas.itemconfig(self.temp_img, state="normal")
        self.canvas.itemconfig(self.mmode_img, state="normal")
        self.canvas.itemconfig(self.power_img, state="normal")                
        self.canvas.itemconfig(self.speedometer_back, state="normal")
        self.canvas.itemconfig(self.speedometer_front, state="normal")
        self.canvas.itemconfig(self.speed_text, state="normal")
        
    
    def show_data_other(self, error_code, key_state, e_stop, state, fwver, hwver):
        # hiding irrelevant data 
        self.canvas.itemconfig(self.brake_overlay, state="hidden")
        self.canvas.itemconfig(self.temp_text, state="hidden")
        self.canvas.itemconfig(self.battery_text, state="hidden")
        self.canvas.itemconfig(self.current_text, state="hidden")
        self.canvas.itemconfig(self.mode_text, state="hidden")
        self.canvas.itemconfig(self.power_percent, state="hidden")
        self.canvas.itemconfig(self.lights, state="hidden")
        self.canvas.itemconfig(self.light_img, state="hidden")
        self.canvas.itemconfig(self.power_img, state="hidden")
        self.canvas.itemconfig(self.mmode_img, state="hidden")
        self.canvas.itemconfig(self.battery_img, state="hidden")
        self.canvas.itemconfig(self.temp_img, state="hidden")
        self.canvas.itemconfig(self.brake_img, state="hidden")
        self.canvas.itemconfig(self.current_img, state="hidden")
        self.canvas.itemconfig(self.speedometer_back, state="hidden")
        self.canvas.itemconfig(self.speedometer_front, state="hidden")
        self.canvas.itemconfig(self.speed_text, state="hidden")

        self.set_power(0)

        # showing relevant data
        self.canvas.itemconfig(self.err_code, text=f"Error code: {error_code}", state="normal")
        self.canvas.itemconfig(self.key_state, text=f"Key: {key_state}", state="normal")
        self.canvas.itemconfig(self.e_stop, text=f"Emergency break: {e_stop}", state="normal")
        self.canvas.itemconfig(self.fwver, text=f"Firmware version: {fwver}", state="normal")
        self.canvas.itemconfig(self.hwver, text=f"Hardware: {hwver}", state="normal")
        self.canvas.itemconfig(self.sysstate, text=f"{state}", state="normal")
        self.canvas.itemconfig(self.estop_img, state="normal")
        self.canvas.itemconfig(self.err_code_img, state="normal")
        self.canvas.itemconfig(self.key_img, state="normal")
        self.canvas.itemconfig(self.fwver_img, state="normal")
    
    def show_break_screen(self):
        self.canvas.itemconfig(self.brake_overlay, state="normal")
        self.canvas.tag_raise(self.brake_overlay)
        self.canvas.itemconfig(self.brake_img, state="normal")
        self.canvas.tag_raise(self.brake_img)
        
    def read_UART(self):
        global uart_conf

        try:
            # Try UART first
            line = uart_conf.readline().decode().strip()
            data = json.loads(line)

        except:
            base_path = os.path.dirname(__file__)
            file_path = os.path.join(base_path, "temp_info.json")

            with open(file_path, "r") as file:
                data = json.load(file)


        if (data["ctrl"]["state"] == "DRIVE"):
            if (data["ctrl"]["break_active"] == "true"):
                self.show_break_screen()
            else:
                self.set_speed(data["drive"]["speed"])
                self.show_data_drive(
                    data["drive"]["temperature"], 
                    data["drive"]["battery_percentage"], 
                    data["drive"]["motor_current"], 
                    data["drive"]["motor_mode"],
                    data["ctrl"]["cmd"],
                    data["ctrl"]["light_active"],
                    "Drive")
        elif (data["ctrl"]["state"] == "ERROR" or data["ctrl"]["state"] == "INIT"):
            if (data["ctrl"]["state"] == "ERROR"):
                sysstate = "Error"
            elif (data["ctrl"]["state"] == "INIT"):
                sysstate = "Initialisation"
            self.show_data_other(data["ctrl"]["fault_code"], 
                                 data["ctrl"]["enable_active"], 
                                 data["ctrl"]["estop_active"],
                                 sysstate,
                                 data["FW_ver"],
                                 data["HW_ver"]
                                 )

# init window
main_window = tk.Tk()
main_window.title("Speedometer")
main_window.configure(bg="black")

ui = speedometer(main_window)
ui.pack()

# main loop for UART updates
def main_loop():
    ui.read_UART()
    main_window.after(100, main_loop)

main_loop()
main_window.mainloop()

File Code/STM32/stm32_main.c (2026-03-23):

#include "main.h"
#include <string.h>
#include <stdio.h>

#define RX_BUFFER_SIZE 256

char rx_buffer[RX_BUFFER_SIZE];
uint16_t rx_index = 0;

//to put in main while(1)
//this code acts only as a bridge and isn't doing any processing (yet)

uint8_t byte;

if(HAL_UART_Receive(&huart1, &byte, 1, 0) == HAL_OK) //agis comme pass through bridge

    if(HAL_UART_Receive(&huart1, &byte, 1, 0) == HAL_OK)
    {
        HAL_UART_Transmit(&huart2, &byte, 1, HAL_MAX_DELAY);
    }

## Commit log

2026-03-23 New
    fhjsdahjflkas
    [Temp_components.xlsx]
2026-03-23 Add BOM
    [Bill of Material PCB.xlsx, Temp_components.xlsx]
2026-04-13 Plan de test
    [PlanDeTest.xlsx]
2026-04-13 Update journal de bord
2026-04-20 new images 2
    [support_pcb.stl]
2026-04-20 Create stm32main
2026-04-20 Plan de test2
    [PlanDeTest.xlsx]
2026-05-11 cleaning and updating
    [Support_MODEL.stl, support_pcb.stl]
